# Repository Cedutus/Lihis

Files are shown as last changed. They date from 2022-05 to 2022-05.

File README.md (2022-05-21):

# Lihis
Lihis is a keyboard made by Eetu for Eetu. It's basically a worse Helix using a Blackpill.

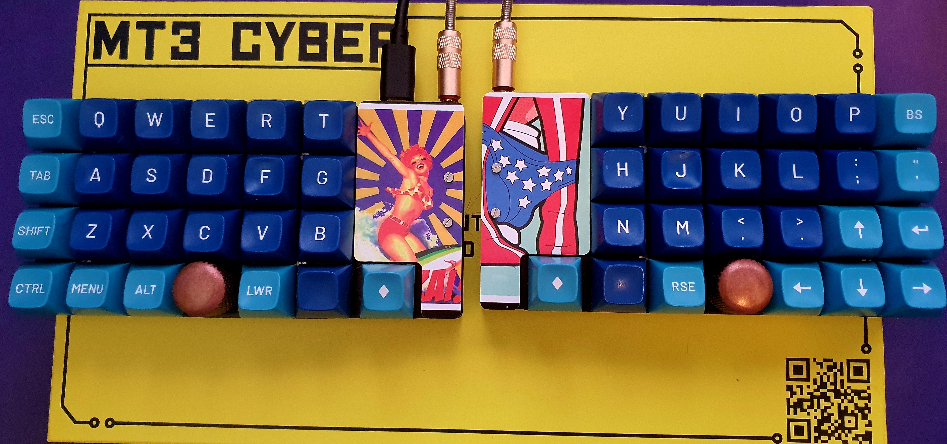
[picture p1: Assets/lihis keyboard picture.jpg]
Lihis

# Parts
 - 48x Hotswap sockets (MX or Choc or both)
 - 48x Diodes (Through hole or SMD)
 - 1x 10k resistor (Trough hole)
 - 2x Blackpill controller  (F401 or F411)
 - 2x Headphone jack
 - 12x 5mm or shorter M2 screws
 -  4x 12mm M2 spacer
 - 8x 10mm M2 spacer
 - 2x Rotary encoder with caps (optional)

# Build guide
 - Solder diodes on the PCB
 - Solder hotswap sockets on the PCB
 - Solder 10k resistor into one of the PCB's
 - Solder the headphone jack on the topside depending on your half
 - Solder Blackpills with the buttons facing up. B12 to Square pad
 - Optional: Solder rotary encoders

Firmware is not included in QMK repo, you will have to compile it yourself. Most of the code is copied and stripped down from Vattern's Grandiceps keyboard.
Blackpill bootloader: hold down the boot button on the blackpill, then press NRST. it might take some tries.

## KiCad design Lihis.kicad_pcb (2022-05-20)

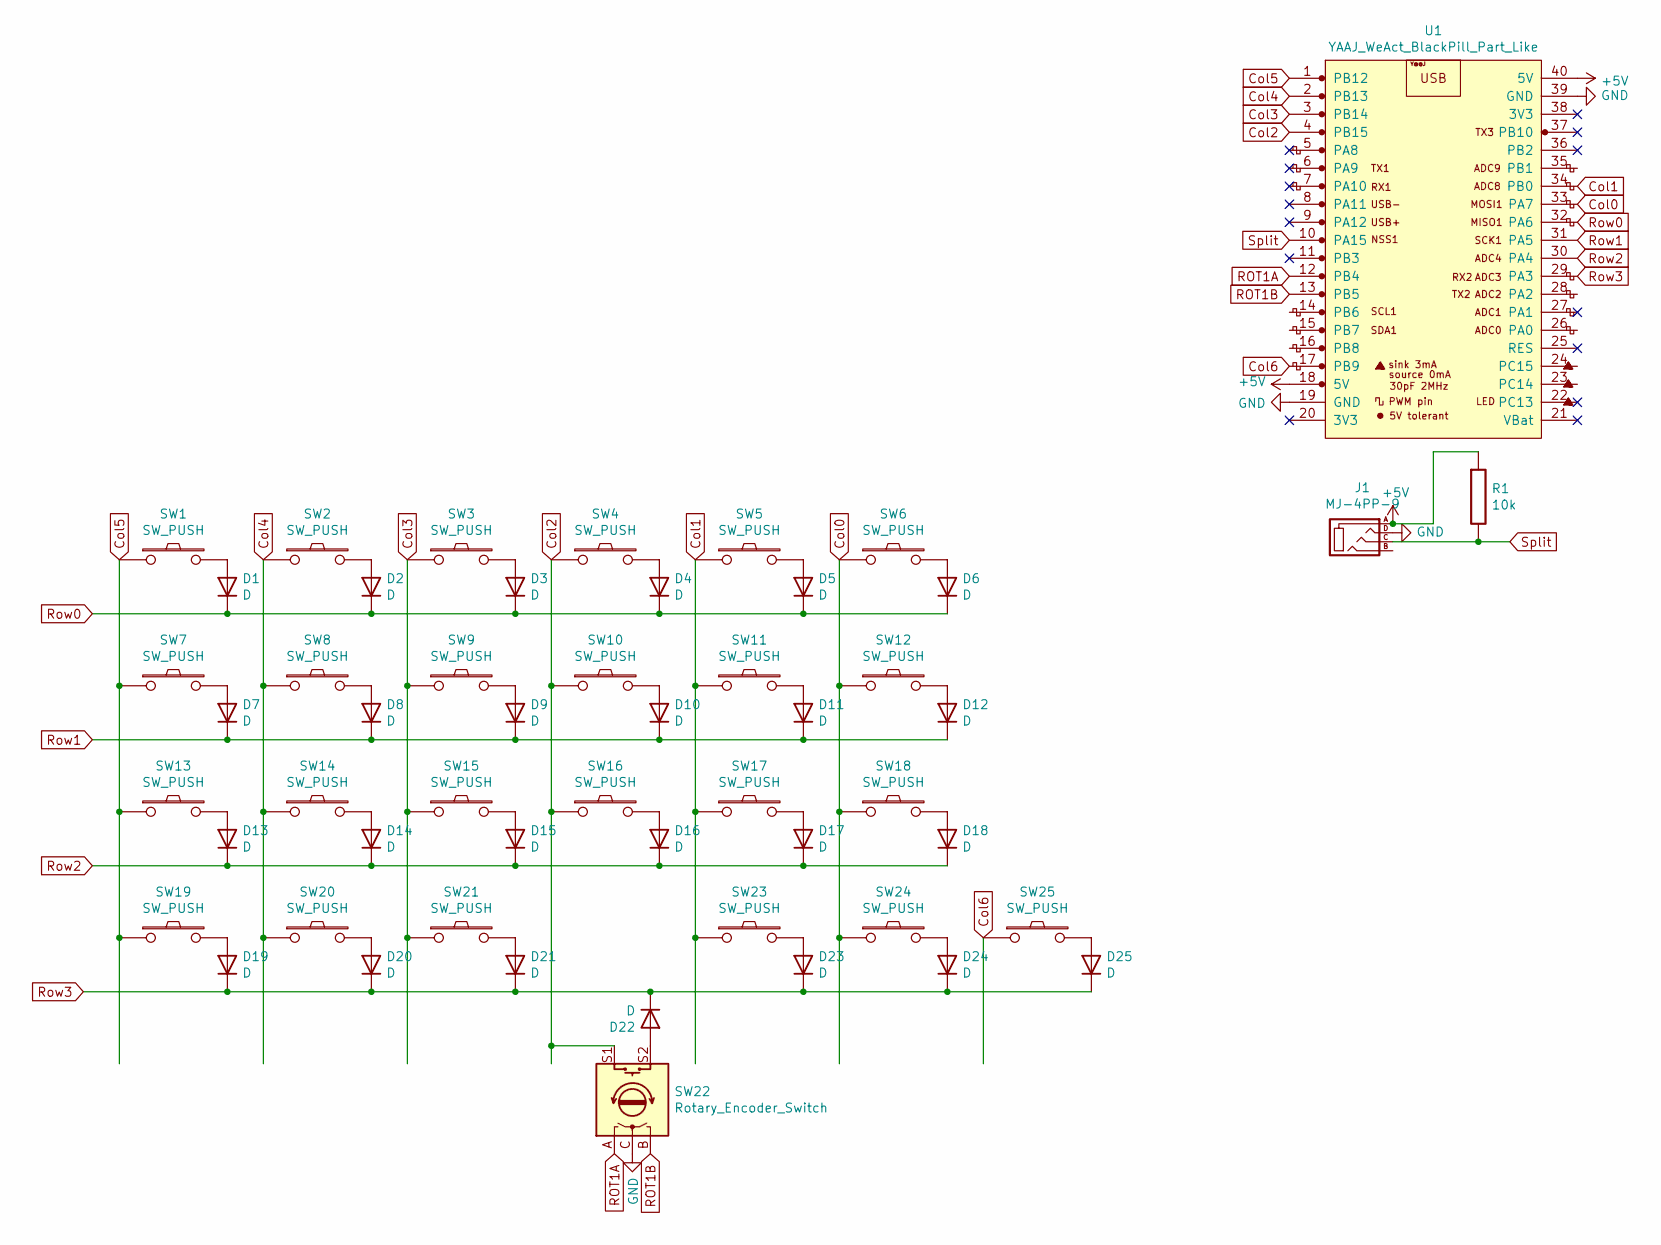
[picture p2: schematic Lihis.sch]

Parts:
D1, D2, D3, D4, D5, D6, D7, D8, D9, D10, D11, D12, D13, D14, D15, D16, D17, D18, D19, D20, D21, D22, D23, D24, D25: D; D_SOD123_axial_flip
J1: MJ-4PP-9
R1: 10k; R
SW1, SW2, SW3, SW4, SW5, SW6, SW7, SW8, SW9, SW10, SW11, SW12, SW13, SW14, SW15, SW16, SW17, SW18, SW19, SW20, SW21, SW23, SW24, SW25: SW_PUSH; CherryMX_Choc_Hotswap
SW22: Rotary_Encoder_Switch; RotaryEncoder_EC11
U1: YAAJ_WeAct_BlackPill_Part_Like; YAAJ_WeAct_BlackPill_22

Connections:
+5V: J1.A, R1.1, U1.18 (5V), U1.40 (5V)
Col0: SW6.1, SW12.1, SW18.1, SW24.1, U1.33 (PA7)
Col1: SW5.1, SW11.1, SW17.1, SW23.1, U1.34 (PB0)
Col2: SW4.1, SW10.1, SW16.1, SW22.S1, U1.4 (PB15)
Col3: SW3.1, SW9.1, SW15.1, SW21.1, U1.3 (PB14)
Col4: SW2.1, SW8.1, SW14.1, SW20.1, U1.2 (PB13)
Col5: SW1.1, SW7.1, SW13.1, SW19.1, U1.1 (PB12)
Col6: SW25.1, U1.17 (PB9)
GND: J1.D, SW22.C, U1.19 (GND), U1.39 (GND)
unnamed: D1.2 (A), SW1.2
unnamed: D2.2 (A), SW2.2
unnamed: D3.2 (A), SW3.2
unnamed: D4.2 (A), SW4.2
unnamed: D5.2 (A), SW5.2
unnamed: D6.2 (A), SW6.2
unnamed: D7.2 (A), SW7.2
unnamed: D8.2 (A), SW8.2
unnamed: D9.2 (A), SW9.2
unnamed: D10.2 (A), SW10.2
unnamed: D11.2 (A), SW11.2
unnamed: D12.2 (A), SW12.2
unnamed: D13.2 (A), SW13.2
unnamed: D14.2 (A), SW14.2
unnamed: D15.2 (A), SW15.2
unnamed: D16.2 (A), SW16.2
unnamed: D17.2 (A), SW17.2
unnamed: D18.2 (A), SW18.2
unnamed: D19.2 (A), SW19.2
unnamed: D20.2 (A), SW20.2
unnamed: D21.2 (A), SW21.2
unnamed: D22.2 (A), SW22.S2
unnamed: D23.2 (A), SW23.2
unnamed: D24.2 (A), SW24.2
unnamed: D25.2 (A), SW25.2
ROT1A: SW22.A, U1.12 (PB4)
ROT1B: SW22.B, U1.13 (PB5)
Row0: D1.1 (K), D2.1 (K), D3.1 (K), D4.1 (K), D5.1 (K), D6.1 (K), U1.32 (PA6)
Row1: D7.1 (K), D8.1 (K), D9.1 (K), D10.1 (K), D11.1 (K), D12.1 (K), U1.31 (PA5)
Row2: D13.1 (K), D14.1 (K), D15.1 (K), D16.1 (K), D17.1 (K), D18.1 (K), U1.30 (PA4)
Row3: D19.1 (K), D20.1 (K), D21.1 (K), D22.1 (K), D23.1 (K), D24.1 (K), D25.1 (K), U1.29 (PA3)
Split: J1.C, R1.2, U1.10 (PA15)

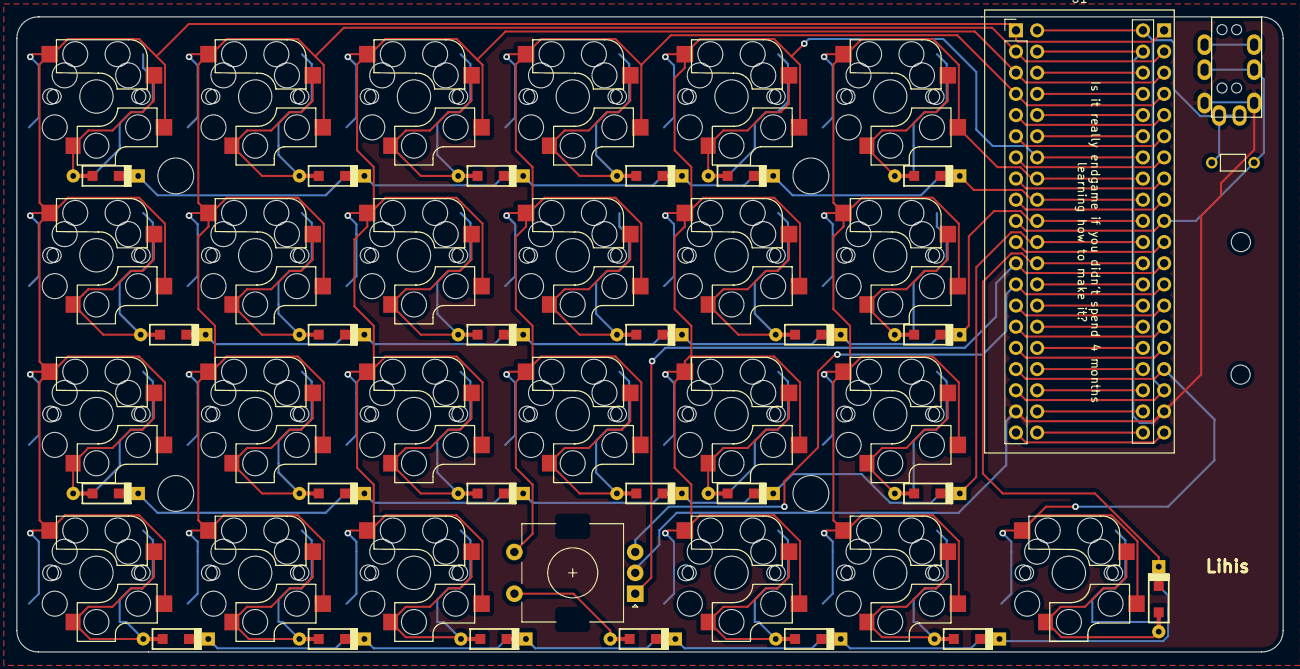
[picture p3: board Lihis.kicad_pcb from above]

Board: 2 copper layers, 151.9 x 76.2 mm, 59 parts (0 on the bottom side), 41 nets.

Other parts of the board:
 : Val**; M2_HOLE_v2
  : Val**; M2_HOLE_v2
 #2,  #3: Val**; M2_HOLE_v2
Ref**: Val**; thread_m2
Ref**#2: Val**; thread_m2

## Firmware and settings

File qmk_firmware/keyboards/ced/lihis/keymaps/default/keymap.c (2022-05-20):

/* Copyright 2022 Eetu Harjunpää
 *
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
 * You should have received a copy of the GNU General Public License
 * along with this program.  If not, see <http://www.gnu.org/licenses/>.
 */
#include QMK_KEYBOARD_H


const uint16_t PROGMEM keymaps[][MATRIX_ROWS][MATRIX_COLS] = {

	[0] = LAYOUT(
	  KC_ESC,   KC_Q,   	KC_W,    	KC_E,		KC_R,	KC_T,                     	KC_Y,	KC_U,	KC_I,    	KC_O,		KC_P,  		KC_BSPC,
	  KC_TAB,   KC_A,   	KC_S,    	KC_D,		KC_F,	KC_G,                     	KC_H,	KC_J,	KC_K,    	KC_L,    	KC_SCLN,  	KC_QUOT,
	  KC_LSFT,	KC_Z,   	KC_X,    	KC_C,		KC_V,	KC_B,                     	KC_N,	KC_M,	KC_COMM,    KC_DOT, 	KC_UP,  	KC_RALT,
	  KC_LCTL,	KC_LGUI,	KC_LALT,	KC_F24,		MO(1),	KC_SPC,	MO(3),	KC_BSPC,	KC_ENT,	MO(2),	KC_PSCR,	KC_LEFT,	KC_DOWN,	KC_RIGHT
	),

	[1] = LAYOUT(
	  KC_DEL,	KC_F1,		KC_F2,    	KC_F3,    	KC_F4,    	KC_F5,             				KC_F6,    	KC_F7,    	KC_F8,    	KC_F9,    	KC_F10,		KC_TRNS,
	  KC_TRNS,	KC_TRNS,	KC_TRNS,    KC_TRNS,    KC_TRNS,    KC_TRNS,                     	KC_TRNS,    KC_TRNS,    KC_TRNS,    KC_TRNS,    KC_TRNS,  	KC_TRNS,
	  KC_TRNS,	KC_TRNS,	KC_TRNS,    KC_TRNS,    KC_TRNS,    KC_TRNS,                     	KC_TRNS,    KC_TRNS,    KC_TRNS,    KC_TRNS, 	KC_TRNS,  	KC_TRNS,
	  KC_TRNS,	KC_TRNS,	KC_TRNS,	KC_TRNS,    KC_TRNS,    KC_TRNS, KC_TRNS,	KC_TRNS,	KC_TRNS,    KC_TRNS, 	KC_TRNS,  	KC_TRNS, 	KC_TRNS,  	KC_TRNS
	),

	[2] = LAYOUT(
	  KC_ESC,	KC_1,   	KC_2,    	KC_3,    	KC_4,    	KC_5,                 				KC_6,    	KC_7,    	KC_8,    	KC_9,    	KC_0,  		KC_TRNS,
	  KC_TRNS,	KC_TRNS,	KC_TRNS,    KC_TRNS,    KC_TRNS,    KC_TRNS,             				KC_TRNS,    KC_TRNS,    KC_TRNS,    KC_TRNS,    KC_LBRC,  	KC_RBRC,
	  KC_TRNS,	KC_TRNS,	KC_TRNS,	KC_TRNS,    KC_TRNS,    KC_TRNS,             				KC_TRNS,    KC_TRNS,    KC_TRNS,    KC_TRNS, 	KC_SLSH,  	KC_TRNS,
	  KC_TRNS,	KC_TRNS,	KC_TRNS,	KC_TRNS,    KC_TRNS,    KC_TRNS,	KC_TRNS,	KC_TRNS,	KC_TRNS,    KC_TRNS, 	KC_TRNS,  	KC_TRNS, 	KC_TRNS,  	KC_TRNS
	),

	[3] = LAYOUT(
	  KC_ESC,	KC_1,		KC_2,    	KC_3,    	KC_4,    	KC_5,       						KC_6,    	KC_7,    	KC_8,    	KC_9,    	KC_0, 		LSFT_T(KC_MINS),
	  KC_TRNS,	KC_TRNS,	KC_TRNS,    KC_TRNS,    KC_TRNS,    KC_TRNS,                            KC_TRNS,    KC_TRNS,    KC_MINS,    KC_EQL,		KC_TRNS,  	KC_NUHS,
	  KC_TRNS,	KC_NUBS,	KC_TRNS,    KC_TRNS,    KC_TRNS,    KC_TRNS,                            KC_TRNS,    KC_TRNS,    KC_TRNS,    KC_TRNS, 	KC_SLSH,  	KC_RBRC,
	  KC_TRNS,	KC_TRNS,	KC_TRNS,    KC_TRNS,    KC_TRNS,    KC_TRNS,	KC_TRNS,	KC_TRNS,	KC_TRNS,    KC_TRNS, 	KC_TRNS,  	KC_TRNS, 	KC_TRNS,  	KC_TRNS
	)
};
#ifdef ENCODER_ENABLE
bool encoder_update_user(uint8_t index, bool clockwise){
    if (index == 0) { /* First encoder */
        if (clockwise) {
            tap_code_delay(KC_VOLU, 1);
        } else {
            tap_code_delay(KC_VOLD, 1);
        }
    } else if (index == 1) { /* Second encoder */
        if (clockwise) {
            tap_code16(KC_PGUP);
        } else {
            tap_code16(KC_PGDN);
        }
    }
    return false;
}	
#endif

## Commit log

2022-05-24 Non-hotswap version.
    Non-hotswap version for MX and Choc.
    [Lihis.kicad_pcb]
2022-06-03 Add files via upload
    Fixed controller cover to actually accept 1.25u keycaps by removing the innner arc.
    [Lihis_Cover.kicad_pcb, Lihis_Cover.sch]
2022-06-03 Add files via upload
    Updated Controller cover Gerber file

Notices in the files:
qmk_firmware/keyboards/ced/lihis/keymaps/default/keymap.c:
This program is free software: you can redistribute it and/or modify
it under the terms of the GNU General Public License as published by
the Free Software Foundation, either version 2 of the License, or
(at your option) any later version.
